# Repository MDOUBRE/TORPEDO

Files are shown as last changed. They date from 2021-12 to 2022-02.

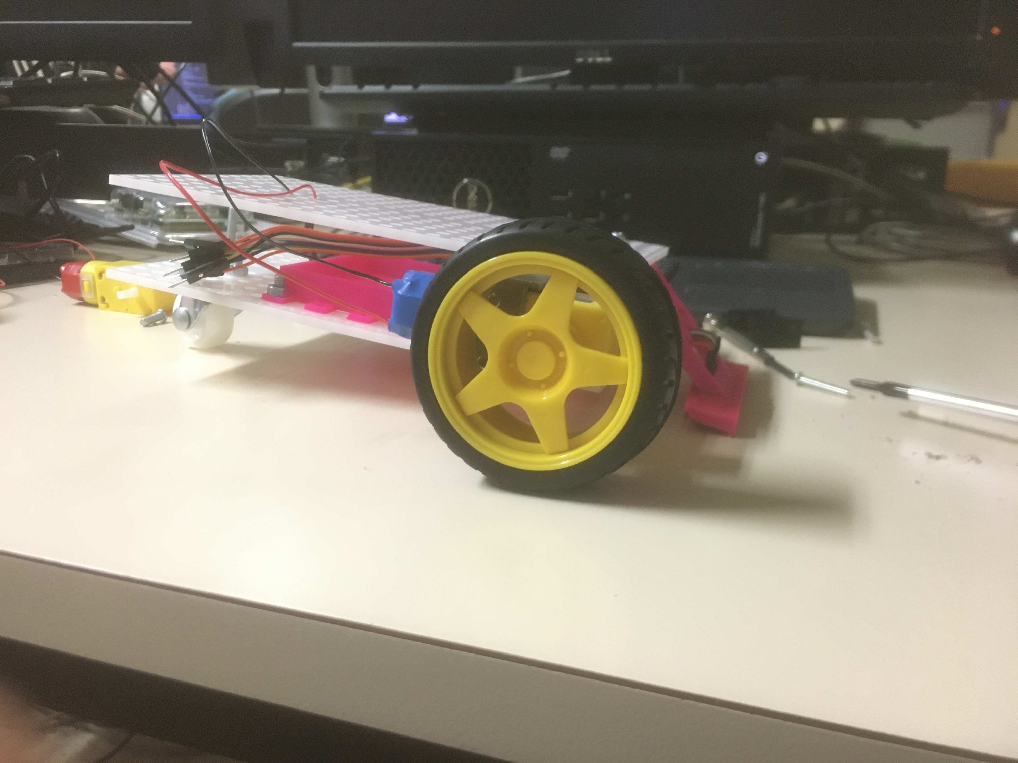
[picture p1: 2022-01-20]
Photos/chassis_v2_6.JPG

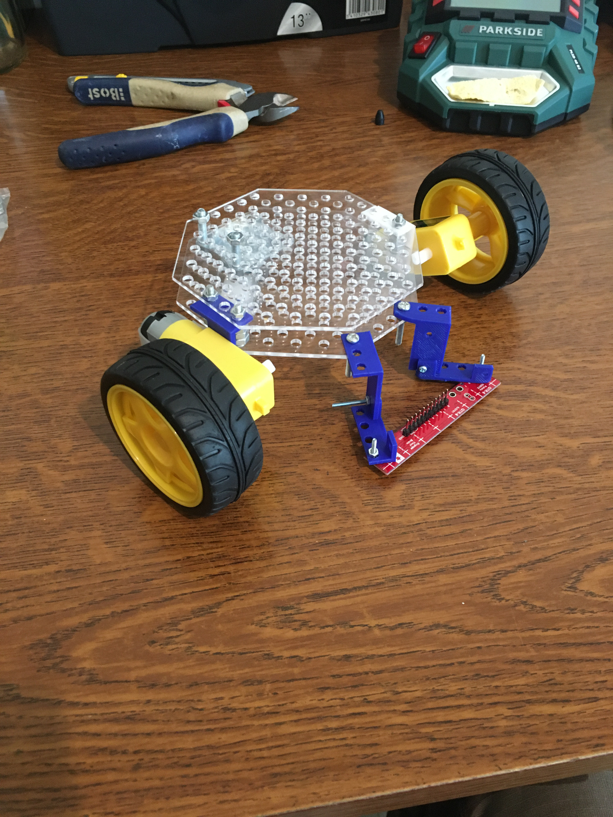
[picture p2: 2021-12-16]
Photos/chassis_v1_1.JPG

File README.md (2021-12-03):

# TORPEDO
Projet TORPEDO

Le projet Torpedo est une projet qui a pour but de concevoir et de réaliser un petit robot autonôme suiveur de lignes.

Il devra à la fin du projet être capable de bouger dans une grille en suivant des lignes et/ou en changeant de directions quand il passera sur un croisement jusqu'à trouver une case de couleur et d'y déposer une caisse de couleur identique.
Il y aura trois cases de couleur sur la grille.

Pour réaliser ce robot nous devrons relever plusieurs challenges :
- Suivi d'une ligne (droite ou courbe)
- Gestion des intersections
- Détection des couleurs
- Laché de caisse
- Mémorisation de grille en mémoire
- Algo du plus court chemin

Nous avons à notre disposition le matériel suivant :
- 1X STM32
- 2X moteurs
- 1X controlleur de moteurs
- 1X chassis (Fichiers STL)

Les membres de l'équipe sont :
- Maxime DOUBRE - Chef de projet
- Julien BERTRAND - Contributeur
- Guillaume DELOSIERES - Contributeur 
- Juan-Pablo GARCIA - Contributeur

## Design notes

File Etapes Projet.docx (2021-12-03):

Hardware (⅕)

- Châssis :
  - Impression (via STL Cassé) ⇒ Guillaume
  - Assemblage
- Électronique :
  - Soudure des pièces ⇒ Maxime
- Assemblage Châssis / Électronique (composants)
- Câblage

Software (⅗)

- Suivi de ligne ⇒ Maxime, Julien, Guillaume, Juan Pablo
- Intersection ⇒
- Sortie de route ⇒
- Détection des couleurs des cases
- Lâché de caisse
- Reconnaissance de grille dans la mémoire
- Plus court chemin (Dijkstra), ...

Tests (⅕)

- Test suivi de ligne : (⇒ Maxime, Julien, Guillaume, Juan Pablo)
  - ligne droite
  - courbe
- Test intersection :
  - X, T et L
- Test sortie de route
- Test couleurs
- Test lâché de caisses
- Test reconnaissance grille mémoire
- Test Dijkstra

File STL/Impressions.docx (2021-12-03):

FABLAB :

- 1 base
- 1 sensor x2 ( base et capteur )
- 1 moteur
- 1 moteur2
- 1 fixation ( plaque )

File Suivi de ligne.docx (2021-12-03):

Suivi de ligne

Fonctions :

- setMoteur(int, int)
- corrigerPosition

Dans le main dans while(True) et if(etat==avancer):

- On allume les moteurs
- captation capteurs ⇒ dans tableau global
- on appelle corrigerPosition
- On détecte intersection/couleur/sortie/... et changement état

setMoteur(int, int)

- on modifie la puissance envoyée aux moteurs selon valeur int
- vérifier que les int ne dépasse pas une certaine valeur et que ca dépasse pas 100% des moteurs ou -100%

corrigerPosition()

- selon captations on appelle setMoteur
- si tout va bien on appelle accélérer ⇒ setMoteur(+,+)

O O O O O O O O

1 2 3 4 5 6 7 8

Configuration des 8 capteurs lors du suivi de ligne.

- les capteurs 4 et 5 voient du noir
- les capteurs 1, 2, 7 et 8 voient du blanc
- les capteurs 3 et 6 voient du gris ou du blanc selon la largeur de la ligne

définir plusieurs niveaux de gris pour les capteurs

0 | 1 | 2 | 3 | 4 | 5 | 6
0-10 | 11-25 | 26-40 | 41-55 | 56-70 | 71-85 | 86-100

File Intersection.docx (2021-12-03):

Intersection

Fonctions :

- interuption si au moins 5 capteurs cote à cote dans le noir ⇒ etat => intersection (déjà ds le main donc à voir ou coder les interruptions)
- arreterRobot() ⇒ étatEnCours intersection (init, arret, arreté, action, sortie)
- decider()
- agir()

arretRobot() :

- regarder dans tableau global pourcentage moteur et décélérer en conséquence (baisse des moteurs proportionnelle à vitesse

tq % >0 on décrémente de int selon tableau

- changer état intersection ⇒ arreté

décider() :

- appeler les dijkstra et autres...
- par défaut : tourner à gauche si possible

agir() :

- setMoteur() Rotation jusqu’à être sur la nouvelle ligne à suivre et que les capteurs de gauche aient capté du noir si on tourne à gauche
- état = avancer

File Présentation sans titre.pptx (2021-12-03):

## TORPEDO

par un groupe dont on ne citera pas le nom parce qu’il est vraiment éclatax!

## Equipe

BERTRAND Julien - Contributeur
DELOSIERES Guillaume - Contributeur
GARCIA Juan Pablo - Contributeur
DOUBRE Maxime - Chef de projet

## Objectif

## Objectif

## Objectif

## Moyens

X2

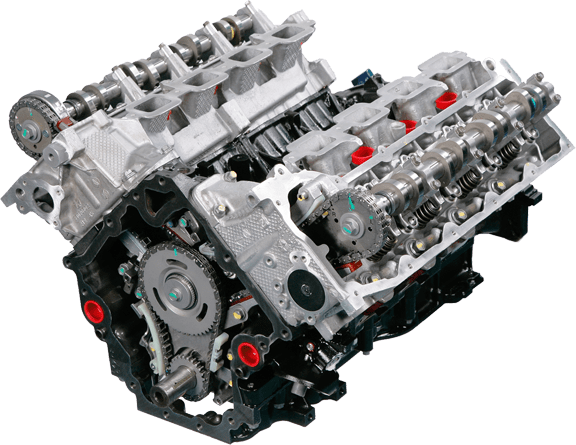
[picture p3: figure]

X1

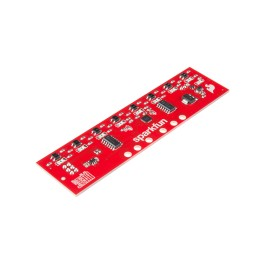
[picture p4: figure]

X1

## Comment ?

## Comment ?

## Comment ?

## Merci

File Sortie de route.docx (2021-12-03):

Sortie de route

Fonctions :

- interruption tout est blanc si pas en état intersection
- arreterRobot()
- demiTour() => on rotate jusqu’à retrouver ligne ou certain nombre de seconde
- spirale() si ligne pas retrouvée

arreterRobot() : voir ds Intersection

demiTour() :

- setMoteur(x, -x) pendant un certain temps ou alors jusqu’à ligne

spirale():

- setMoteur(x, -x) tourner en spirale jusqu’à retrouver une ligne

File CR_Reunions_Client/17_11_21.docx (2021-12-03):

CR Réunion 17 novembre 2021

Sujet : Présentation du sujet de projet, explication de son contenu et fourniture du matériel

Présents :

Client : CASSE Hugues

Equipe Projet : DOUBRE Maxime, BERTRAND Julien, DELOSIERES Guillaume, GARCIA Juan Pablo

Déroulé :

M.CASSE nous a présenté l’ensemble du projet, quel en était l’objectif et ce que nous devions faire pour y parvenir.

Il nous a fourni le matériel nécessaire pour commencer à le mener.

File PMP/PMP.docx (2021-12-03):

DOUBRE Maxime ⇒ Chef de projet

BERTRAND Julien ⇒ Attributeur, Contributeur

DELOSIERES Guillaume ⇒ Contributeur

GARCIA Juan Pablo ⇒ Contributeur

PMP TORPEDO

Table des matières

1. Contexte et objectifs
  a. Projet
  b. Document
  c. Répartition des rôles
2. Avancement du projet
  a. Planning
  b. Liste des tâches techniques
  c. Contraintes du client
3. Réunions
  a. Réunions périodiques avec le client
4. Documents
5. Livrables
6. Qualité
  a. Tests

1. Contexte et objectifs

a. Projet
b. Document
c. Répartition des rôles

DOUBRE Maxime ⇒ Chef de projet

BERTRAND Julien ⇒ Attributeur, Contributeur

DELOSIERES Guillaume ⇒ Contributeur

GARCIA Juan Pablo ⇒ Contributeur

5. Livrables

- Châssis robot
- Code Suivi ligne
- Code Intersection
- Code couleurs et largage caisse
- Code mémoire grille
- Code Dijkstra

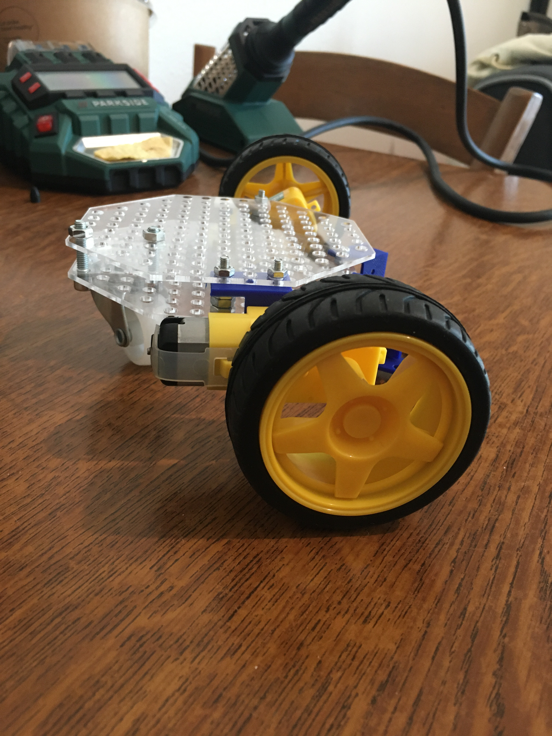
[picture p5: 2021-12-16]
Photos/chassis_v1_3.JPG

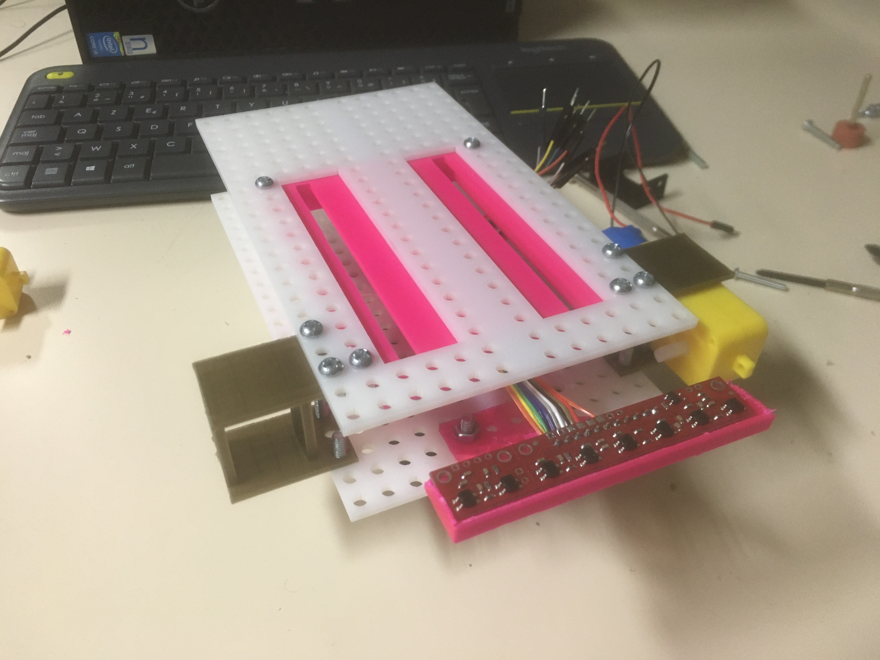
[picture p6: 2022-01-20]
Photos/chassis_v2_1.JPG

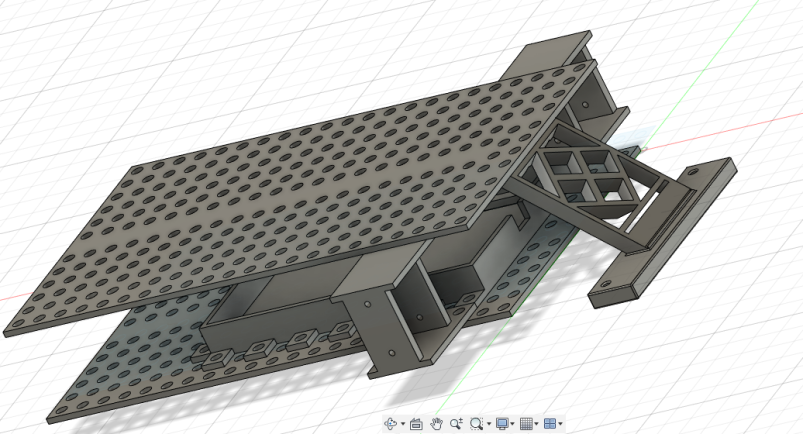
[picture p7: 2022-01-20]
Photos/chassis_v2_stl.png

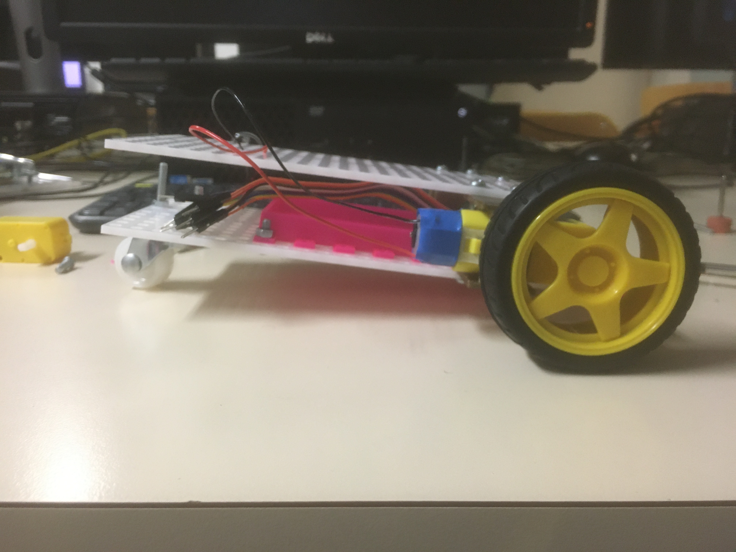
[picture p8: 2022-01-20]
Photos/chassis_v2_5.JPG

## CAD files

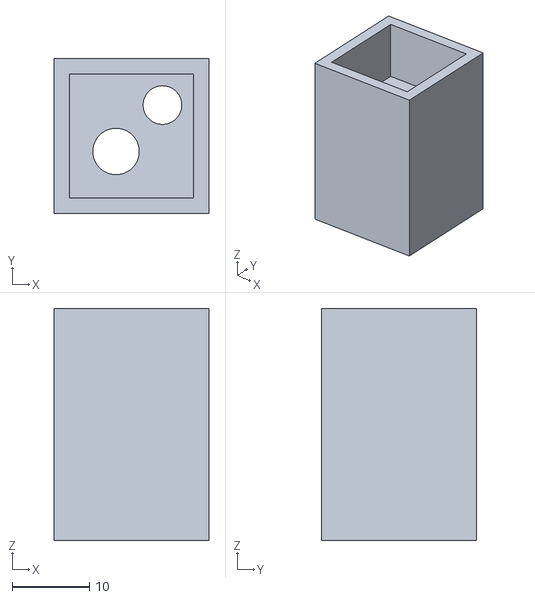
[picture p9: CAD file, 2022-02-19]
STL/detecteur couleur v0.stl
20.0 x 20.0 x 30.0

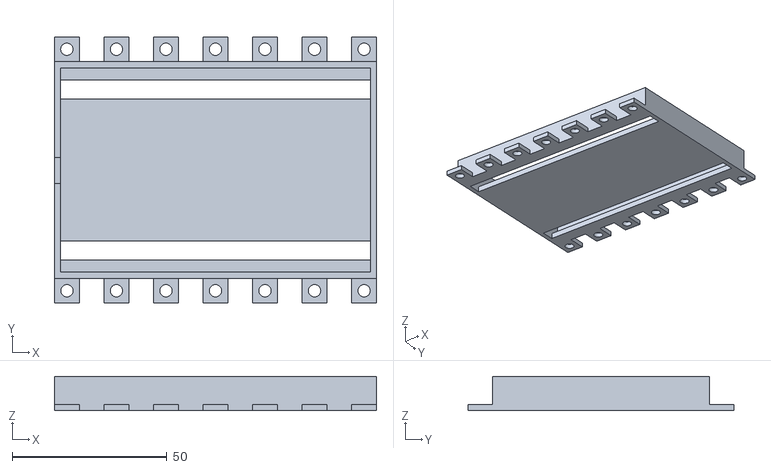
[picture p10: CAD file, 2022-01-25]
STL/bases stm32.stl
104.0 x 86.0 x 11.0

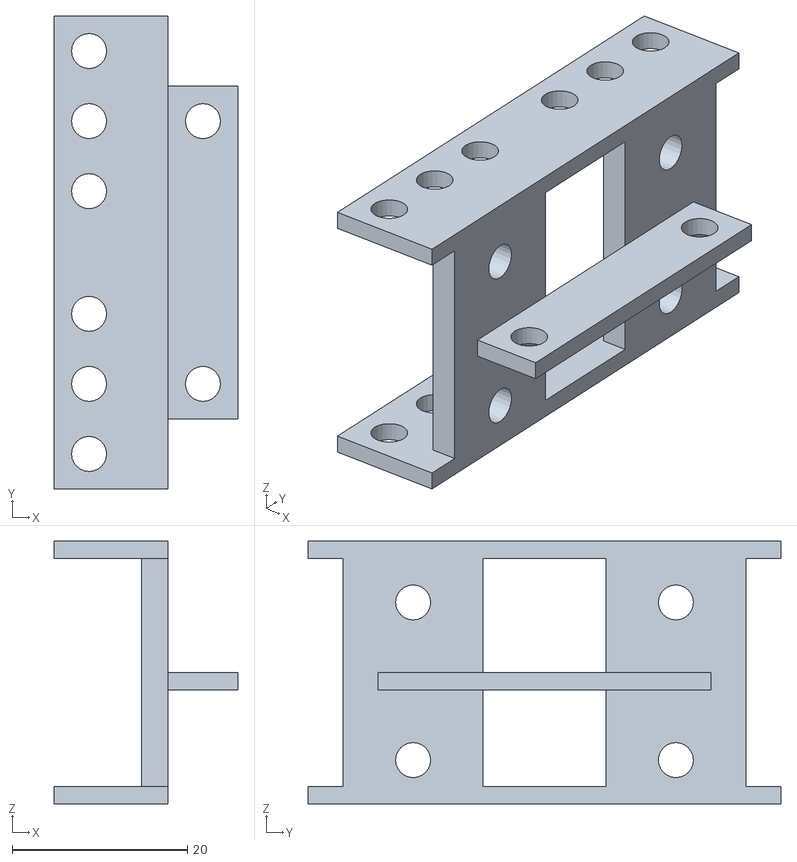
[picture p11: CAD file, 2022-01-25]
STL/roue arriere.stl
21.0 x 54.0 x 30.0

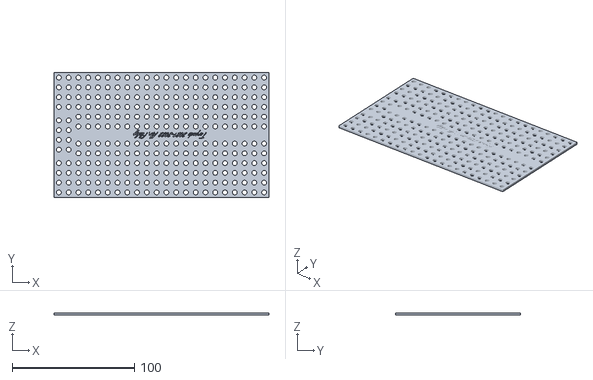
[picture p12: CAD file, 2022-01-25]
STL/Base Haute .stl
176.0 x 102.0 x 2.00

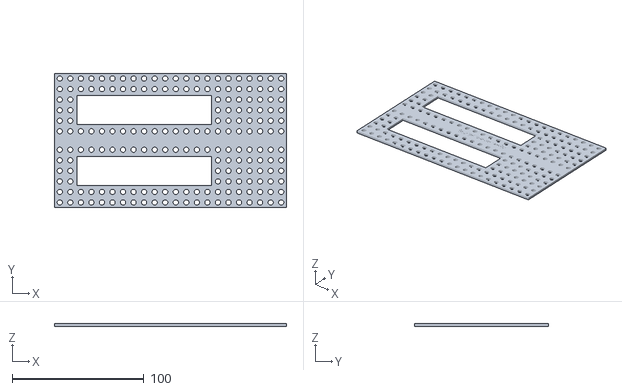
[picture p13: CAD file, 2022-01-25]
STL/Base Bas.stl
176.0 x 102.0 x 2.00

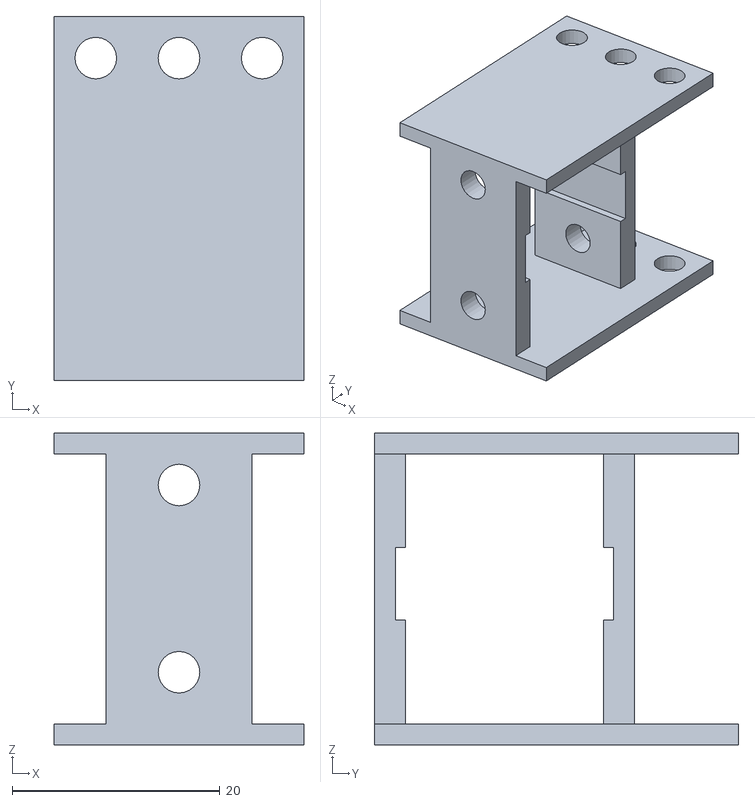
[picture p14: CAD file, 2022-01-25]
STL/Support Moteur V3.stl
24.0 x 35.0 x 30.0

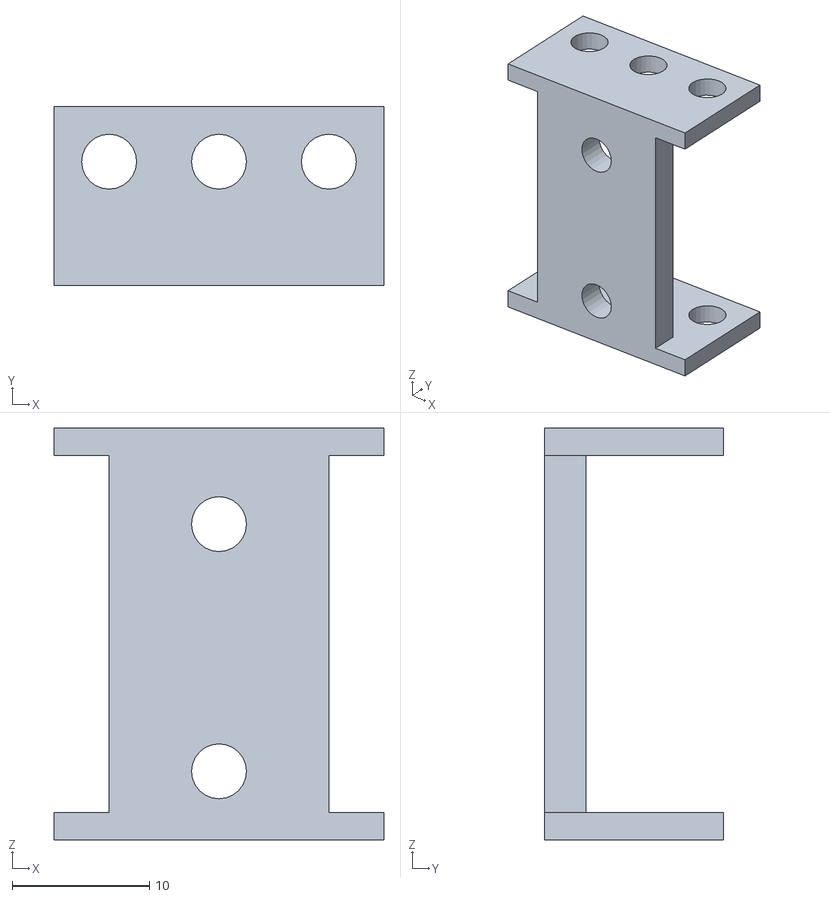
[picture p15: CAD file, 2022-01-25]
STL/Support Moteur Small.stl
24.0 x 13.0 x 30.0

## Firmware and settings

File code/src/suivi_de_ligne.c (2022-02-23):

#include <tinyprintf.h>
#include <stm32f4/rcc.h>
#include <stm32f4/gpio.h>
#include <stm32f4/nvic.h>
#include <stm32f4/exti.h>
#include <stm32f4/syscfg.h>
#include <stm32f4/tim.h>
#include <stm32f4/adc.h>


// GPIOD
//#define X P
#define C1 0                            
#define C2 1                            
#define C3 2                            
#define C4 3                            
#define C5 4                            
#define C6 5                           
#define C7 6                            
#define C8 7    


// GPIODA

#define WAIT_PSC 1  //T * 42MHz / 2¹⁶
#define WAIT_DELAY (APB1_CLK / WAIT_PSC)
#define HALF_PERIOD 42000

#define SEUIL_BLANC	4
#define SEUIL_NOIR	8

volatile int puiss_MD = 0; //[0-100] puissance moteur droit
volatile int puiss_MG = 0; //[0-100] puissance moteur gauche
int sens_MD = 0; //[0,1] sens moteur droit
int sens_MG = 0; //[0,1] sens moteur gauche

#define MD1 4
#define MD2 6
#define MG1 5
#define MG2 7
#define MODE 8

#define SM 4

#define TIM3_DIV 8
#define TIM3_PERIOD	60000

#define KP_MD
#define KI_MD
#define KD_MD
#define KP_MG
#define KI_MG
#define KD_MG

volatile int un_sur_deux = 0;
volatile int TIM4_triggered = 0;
volatile int KP = 144; //Constante Proportionnelle
volatile int P = 0 ; // Error
volatile int KI = 1; //Constante Integrale
volatile int I = 0; //I = I + error (P)
volatile int KD = 108; //Constante Derivée
volatile int D = 0; //D= error - previousError 
volatile int PAvant = 0; // Previous error
volatile int PID = 0;
volatile enum{ OUT,LINE,INTERSECTION} etat = OUT;
volatile enum{ T,LL,LR,X,TL,TR,TR1,TR2,TR3,TL1,TL2,TL3} type = T;
volatile int d = 0;
volatile short int demitour = 0;


// Variable du chemin

volatile enum{ N, E, S ,O} direction = O; // direction de depart
#define TAILLE_GRILLE 30 // <= 32 ; Nombre de points de la grille, inférieur ou égale à 32
#define CHEMIN_MAX 10    // Nombre de points du chemin, inférieur ou égale à 32,
//tableau contenant une suite de direction 
//Il sert à guider le véhicule entre 2 points clés du chemin
volatile short int chemin[TAILLE_GRILLE];
// Points clés du chemin
// le vehicule s'arrètera au dernier point du tableau ou à la première occurence de -1
// le premier point du tableau est le premier point rencontré
// attention à bien orienté le véhicule
volatile short int checkpoint[CHEMIN_MAX] = {12 , 10  , 0 , 4 , 29 , 25 , 10 , 14 , 13 , -1};
// largage de caisse
// le vehicule activera le servo-moteur quand il y a une valeur differente de 0
// le premier point de TAB_SM correspond au premier point de checkpoint
volatile short int TAB_SM[CHEMIN_MAX] =     {0 ,  0  , 1  ,  0 , 1 , 0  , 0  , 0  , 0 , 0 };


// calcul du temps entre de le moment ou la ligne d'un capteur est montee a 1 et le moment ou elle retombe a 0
// passer la ligne du capteur en outpout avec pull up
// attendre 10 microseconde pour que la ligne soit a 1
// passer la ligne en inpout -> la tension de la ligne va diminuer jusqu'a etre nulle 
// calculer le temps de descente a 0

// structure de représentation des points
// chaque point est représenté par ces voisins orientés
struct croisement
{
    int nord; //point au nord du sommet
    int est; //point à l'est du sommet
    int ouest; //point à l'ouest du sommet
    int sud; //point au sud du sommet
};
typedef struct croisement croisement;


//fonction d'analyse du retour capteur
// retourne une valeur entre -7 et +7 pour le PID afin de corriger le décalage par rapport à la ligne
// retourne 10 en cas de sortie de route
// retourne 11 en cas de croisement en T
// retourne 12 en cas de virage à gauche
// retourne 13 en cas de virage à droite
int get_error(short int * array){

	unsigned char TB = 0b00000000;
	unsigned char TBT;
	for (short int i =0 ; i < 8; i++){
		TB = TB << 1;
		printf("%d\n", array[i]);
		if (array[i]> 6){
			TB = TB | 0b00000001;
		}
		
	}
	printf("%u\n",TB);
	if (!(TB ^ 0b00011000))
	{
		return 0;
	}else if(!(TB ^ 0b00001000))
	{
		return 1;
	}else if(!(TB ^ 0b00001100))
	{
		return 2;
	}else if(!(TB ^ 0b00000100))
	{
		return 3;
	}else if(!(TB ^ 0b00000110))
	{
		return 4;
	}else if(!(TB ^ 0b00000010))
	{
		return 5;
	}else if(!(TB ^ 0b00000011))
	{
		return 6;
	}else if(!(TB ^ 0b00000001))
	{
		return 7;
	}else if(!(TB ^ 0b00010000))
	{
		return -1;
	}else if(!(TB ^ 0b00110000))
	{
		return -2;
	}else if(!(TB ^ 0b00100000))
	{
		return -3;
	}else if(!(TB ^ 0b01100000))
	{
		return -4;
	}else if(!(TB ^ 0b01000000))
	{
		return -5;
	}else if(!(TB ^ 0b11000000))
	{
		return -6;
	}else if(!(TB ^ 0b10000000))
	{
		return -7;
	}else if(!(TB ^ 0b00000000))
	{
		return 10;
	}else
	{
		TBT = (TB & 0b11111000);
		if(!(TBT ^ 0b11111000) || !(TBT ^ 0b11110000) || !(TBT ^ 0b11101000) || !(TBT ^ 0b11011000) || !(TBT ^ 0b10111000) || !(TBT ^ 0b01111000)) 
		{
			TBT = (TB & 0b00011111);
			if(!(TBT ^ 0b00011111) || !(TBT ^ 0b00011110) || !(TBT ^ 0b00011101) || !(TBT ^ 0b00011011) || !(TBT ^ 0b00010111) || !(TBT ^ 0b000001111)) 
			{
				return 11;
			}
			return 12;
		}else 
		{
			TBT = (TB & 0b00011111);
			if(!(TBT ^ 0b00011111) || !(TBT ^ 0b00011110) || !(TBT ^ 0b00011101) || !(TBT ^ 0b00011011) || !(TBT ^ 0b00010111) || !(TBT ^ 0b000001111)) 
			{
				return 13;
			}
		}
	}
	return 0;
}

void handle_TIM4() {
	TIM4_ARR = HALF_PERIOD;
    if(un_sur_deux!=1){    
		TIM4_triggered = 1;
        
        un_sur_deux+=1;
    }
    else{
        un_sur_deux=0;
    }
	
	TIM4_SR &= ~TIM_UIF;
}

void init_TIM4(){
	DISABLE_IRQS;

	NVIC_ICER(TIM4_IRQ >> 5) |= 1 << (TIM4_IRQ & 0X1f);
	NVIC_IRQ(TIM4_IRQ) = (uint32_t)handle_TIM4;
	NVIC_IPR(TIM4_IRQ) = 0;

	NVIC_ICPR(TIM4_IRQ >> 5) |= 1 << (TIM4_IRQ & 0X1f);
	NVIC_ISER(TIM4_IRQ >> 5) |= 1 << (TIM4_IRQ & 0X1f);

	TIM4_CR1 = 0;
	TIM4_PSC = WAIT_PSC;
	TIM4_ARR = HALF_PERIOD;
	TIM4_EGR = TIM_UG;
	TIM4_SR = 0;
	TIM4_CR1 = TIM_ARPE;
	TIM4_SR &= ~TIM_UIF;
	TIM4_DIER = TIM_UIE;

	ENABLE_IRQS;
	TIM4_CR1 |= TIM_CEN;
}


void init(){
    
	

}

// fonction de charge des capteurs
// Fait passer toutes les lignes des capteurs en OUT et PULL UP
void CHARGE()
{
	for (short int i=0; i < 4; i++)                              
	{
		GPIOA_MODER = SET_BITS(GPIOA_MODER, i*2, 2, 0b01); //set GPIO A 
		GPIOA_OTYPER = GPIOA_OTYPER & ~(1 << i);
		GPIOA_PUPDR = SET_BITS(GPIOA_PUPDR, i*2, 2, 0b01);

		GPIOD_MODER = SET_BITS(GPIOD_MODER, i*2, 2, 0b01); //set GPIO D
		GPIOD_OTYPER = GPIOD_OTYPER & ~(1 << i);
		GPIOD_PUPDR = SET_BITS(GPIOD_PUPDR, i*2, 2, 0b01);
	}
}

// fonction de charge des capteurs
// Fait passer toutes les lignes des capteurs en IN et PULL UP

void CAPTURE_START()
{
	for (short int i=0; i < 4; i++)                             
	{
		GPIOA_MODER = SET_BITS(GPIOA_MODER, i*2, 2, 0b00); //set GPIO A 
		GPIOA_OTYPER = GPIOA_OTYPER & ~(1 << i);
		GPIOA_PUPDR = SET_BITS(GPIOA_PUPDR, i*2, 2, 0b01);

		GPIOD_MODER = SET_BITS(GPIOD_MODER, i*2, 2, 0b00); //set GPIO D
		GPIOD_OTYPER = GPIOD_OTYPER & ~(1 << i);
		GPIOD_PUPDR = SET_BITS(GPIOD_PUPDR, i*2, 2, 0b01);
	}
	
}

void init_moteurs(){
    //init des deux pins pour le moteur 1
    GPIOB_MODER = SET_BITS(GPIOB_MODER, 2*MD1, 2, 0b10);
    GPIOB_AFRL = SET_BITS(GPIOB_AFRL, 4*MD1, 4, 2);
    GPIOB_OTYPER &= ~(1 << MD1);
    GPIOB_MODER = SET_BITS(GPIOB_MODER, 2*MD2, 2, 0b01);
	GPIOB_OTYPER &= ~(1 << MD2);
	GPIOB_PUPDR = SET_BITS(GPIOB_PUPDR, 2*MD2, 2, 0b01);

    // init des deux pins pour le moteur 2
    GPIOB_MODER = SET_BITS(GPIOB_MODER, 2*MG1, 2, 0b10);
    GPIOB_AFRL = SET_BITS(GPIOB_AFRL, 4*MG1, 4, 2);
    GPIOB_OTYPER &= ~(1 << MG1);
    GPIOB_MODER = SET_BITS(GPIOB_MODER, 2*MG2, 2, 0b01);
	GPIOB_OTYPER &= ~(1 << MG2);
	GPIOB_PUPDR = SET_BITS(GPIOB_PUPDR, 2*MG2, 2, 0b01);

    // init de la pin pour le mode
    GPIOD_MODER = SET_BITS(GPIOD_MODER, 2*MODE, 2, 0b01);
	GPIOD_OTYPER &= ~(1 << MODE);
	GPIOD_PUPDR = SET_BITS(GPIOD_PUPDR, 2*MODE, 2, 0b01);

    GPIOD_BSRR = 1 << MODE;
}

// pour le moment 20KHz
void init_TIM3() {
	// TIM3
    TIM3_PSC = 0;
	TIM3_ARR = 0xE0F;
	TIM3_CCMR1 = TIM_CCS1S_OUT | TIM_OC1M_PWM1 | TIM_CCS2S_OUT | TIM_OC2M_PWM1;
    //TIM3_CCMR2 = TIM_CCS2S_OUT | TIM_OC2M_PWM1;
	TIM3_CCER = TIM_CC1E | TIM_CC2E;
	TIM3_CCR1 = 0;
	TIM3_CCR2 = 0;
	TIM3_CR1 = TIM_CEN | TIM_ARPE;
    //TIM3_CR2 = TIM_CEN | TIM_ARPE;
}

void start_MD() {
	TIM3_CCR1 = TIM3_ARR;
}

void stop_MD() {
	TIM3_CCR1 = 0;
}

void set_MD(int pulse) {

	puiss_MD = pulse;
    TIM3_CCR1 =pulse;
	//TIM3_CCR1 = 0;
}

void inverseMD(){
    if(GPIOB_ODR & (1<<MD2)){
        GPIOB_BSRR = 1 << (MD2 + 16);
    }
    else{
        GPIOB_BSRR = 1 << MD2;

    }
}

void start_MG() {
	TIM3_CCR2 = TIM3_ARR;
}

void stop_MG() {
	TIM3_CCR2 = 0;
}

void set_MG(int pulse) {

	puiss_MG = pulse;
	TIM3_CCR2 = pulse;//TIM_ARR = 20k, TIM_CCR2 va de 0 a 20k
	//TIM3_CCR2 = 0;
}

void inverseMG(){
    if(GPIOB_ODR & (1<<MG2)){
        GPIOB_BSRR = 1 << (MG2 + 16);
    }
    else{
        GPIOB_BSRR = 1 << MG2;
    }
}

//Actualise la vitesse des moteurs en fonction du PID
void VITESSE_PID()
{
	printf("In PID\n");
	puiss_MD = 1080 -PID; //30 % de 3600
	if (puiss_MD <0){
		puiss_MD = 0;
	}
	puiss_MG = 1980 - puiss_MD;
	set_MD(puiss_MD);
	set_MG(puiss_MG);
	
	printf("Vitesse M1: %d, Vitesse M2 %d\n", puiss_MD, puiss_MG);
}

//Diminue légèrement la vitesse des moteurs
//Comme la fonction est appelée à chaque cycle, cela permet un arret doux du véhicule
void SMOOTHSTOP()
{
	if(puiss_MD >= 25)
	{
		set_MD(puiss_MD - 25);
        if(puiss_MD >= 25 + puiss_MG)
        {
            set_MG(puiss_MD - 25);
        }
	}
	else
	{
		set_MD(0);
	}
	if(puiss_MG >= 25)
	{
		set_MG(puiss_MG - 25);
        if(puiss_MG >= 25 + puiss_MD)
        {
            set_MG(puiss_MG - 25);
        }
	}
	else
	{
		set_MG(0);
	}
    

}

int calculer_chemin(short int start, short int end);
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
int main() {
	printf("\nStarting...\n");

	// RCC init
	RCC_AHB1ENR |= RCC_GPIOAEN;
	RCC_AHB1ENR |= RCC_GPIODEN;
	RCC_APB1ENR |= RCC_TIM4EN;
	RCC_APB2ENR |= RCC_ADC1EN;
	RCC_AHB1ENR |= RCC_GPIOBEN;
	RCC_APB1ENR |= RCC_TIM3EN;



	// initialisation
	init();
    init_TIM4();
	init_moteurs();
    init_TIM3();
    init_TIM2();
    init_SM();

    if(GPIOB_ODR & (1<<MD2)){
        sens_MD = 0;
    }
    else{
        sens_MD = 1;
    }
    if(GPIOB_ODR & (1<<MG2)){
        sens_MG = 0;
    }
    else{
        sens_MG = 1;
    }

    // calcul chemin du premier trajet entre les deux premiers points clés
    
    printf("initialisation finie\n");

    short int start = checkpoint[d];
    short int end = checkpoint[d+1];

    short int c = calculer_chemin(start,end);
	// main loop
	printf("Endless loop!\n");
    short int x=0;
    int error = 0;
    CHARGE();
    short int vc[8] = { 12 , 12 , 12 , 12 , 12 , 12 , 12 , 12 };
	set_MG(30);
	set_MD(30);
	while(1) {
        if(TIM4_triggered){
			TIM4_triggered = 0;
            //charge les capteurs pendant un cycle puis regarde sur les 10 cycles suivants combien de temps les lignes mettent à se décharger
			for (int i=0; i < 4; i++)                              
            {
                if((vc[i] > x) & ((GPIOA_IDR & (1 << i ))== 0))
                {
                    vc[i] = x;
                }
                if((vc[i+4] > x) & ((GPIOD_IDR & (1 << i ))== 0))
                {
                    vc[i+4] = x;
                }
            }
            if (x == 11)
            {
                
                x = 0;
                printf("%d ; %d ; %d ; %d ; %d ; %d ; %d ; %d\n",vc[0],vc[1],vc[2],vc[3],vc[4],vc[5],vc[6],vc[7]);
                CHARGE();
                switch(etat){
                // cas sortie de route
                case OUT :
					printf("CASE OUT");
                    // passage en suivi de ligne si le véhicule détecte une ligne
                    if  ((vc[3] > SEUIL_NOIR || vc[4] > SEUIL_NOIR) && vc[0] < SEUIL_BLANC && vc[7] < SEUIL_BLANC ){
                        etat = LINE;
						PAvant = 0;
						I = 0;
                        break;
                    }
                    stop_MD();
                    stop_MG();
                    break;
                // cas suivi de ligne
                case LINE:
					printf("CASE LINE");
                    error = get_error(vc);
                    switch(error){
                        // passage en sortie de route
                        case 10:
                            etat = OUT;
                            stop_MD();
                            stop_MG();
                            break;
                        // passage en intersection en T
                        case 11:
                            etat = INTERSECTION;
                            type = T;
                            stop_MD();
                            stop_MG();
                            break;
                        // passage en intersection en L à gauche
                        case 12:
                            etat = INTERSECTION;
                            type = LL;
                            stop_MD();
                            stop_MG();
                            break;
                        // passage en intersection en L à droite
                        case 13:
                            etat = INTERSECTION;
                            type = LR;
                            stop_MD();
                            stop_MG();
                            break;
                        default:
                            P = error;
                            I = I + P;
                            D = P - PAvant;
                            PID = (KP*P) +(KI*I)+ (KD*D);
                            PAvant = P;
                            printf("P: %d, result get_error: %d\n",P,get_error(vc));
                            VITESSE_PID();
                            break;
                    }
                    break;
                // cas intersection
                case INTERSECTION:
                    printf("CASE INTERSECTION\n");
                    
                    switch(type){
                        // sous cas intersection en T
                        case T:
                            printf("CASE T\n");
                            SMOOTHSTOP();
                            // passage en intersection en X
                            if(vc[7] < SEUIL_BLANC && vc[0] < SEUIL_BLANC && (vc[3] > SEUIL_BLANC || vc[4] > SEUIL_BLANC))
                            {
                                type = X;
                                //printf("CX\n");
                            }
                            // quand le véhicule est arrété, appelle la fonction de choix de direction
                            if( puiss_MD == 0 && puiss_MG == 0)
                            {
                                c = choix_direction(c, chemin);
                            }
                            break;
                        // sous cas intersection en L à gauche
                        case LL:
                            printf("CASE LL\n");
                            SMOOTHSTOP();
                            // passage en intersection en T
                            if(vc[7] > SEUIL_NOIR && (vc[3] > SEUIL_BLANC || vc[4] > SEUIL_BLANC))
                            {
                                type = T;
                                //printf("CT\n");
                            }
                            // passage en intersection en T à gauche
                            if(vc[0] < SEUIL_BLANC && (vc[3] > SEUIL_BLANC || vc[4] > SEUIL_BLANC))
                            {
                                type = TL;
                                //printf("CTL\n");
                            }
                            // quand le véhicule est arrété, appelle la fonction de choix de direction
                            if( puiss_MD == 0 && puiss_MG == 0)
                            {
                                c = choix_direction(c, chemin);
                            }
                            break;
                        // sous cas intersection en L à droite
                        case LR:
                            printf("CASE LR\n");
                            SMOOTHSTOP();
                            // passage en intersection en T
                            if(vc[0] > SEUIL_NOIR && (vc[3] > SEUIL_BLANC || vc[4] > SEUIL_BLANC))
                            {
                                type = T;
                                //printf("CT\n");
                            }
                            // passage en intersection en T à droite
                            if(vc[7] < SEUIL_BLANC && (vc[3] > SEUIL_BLANC || vc[4] > SEUIL_BLANC))
                            {
                                type = TR;
                                //printf("CTR\n");
                            }
                            // quand le véhicule est arrété, appelle la fonction de choix de direction
                            if( puiss_MD == 0 && puiss_MG == 0)
                            {
                                c = choix_direction(c, chemin);
                            }
                            break;
                        //sous cas intersection en X
                        case X:
                            printf("CASE X\n");
                            SMOOTHSTOP();
                            // quand le véhicule est arrété, appelle la fonction de choix de direction
                            if( puiss_MD == 0 && puiss_MG == 0)
                            {
                                c = choix_direction(c, chemin);
                            }
                            break;
                        //sous cas intersection en T à gauche
                        case TL:
                            printf("CASE TL\n");
                            SMOOTHSTOP();
                            // quand le véhicule est arrété, appelle la fonction de choix de direction
                            if( puiss_MD == 0 && puiss_MG == 0)
                            {
                                c = choix_direction(c, chemin);
                            }
                            break;
                        //sous cas intersection en T à droite
                        case TR:
                            printf("CASE TR\n");
                            SMOOTHSTOP();
                            // quand le véhicule est arrété, appelle la fonction de choix de direction
                            if( puiss_MD == 0 && puiss_MG == 0)
                            {
                                c = choix_direction(c, chemin);
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

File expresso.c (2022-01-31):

// LED on GPIOD
#define ONOFF_LED		12
#define STARTSTOP_LED	13

// button on GPIOA
#define ONOFF_BUT		PA3
#define STARTSTOP_BUT	P4		

void init_ui() {

	// LEDs
	GPIOD_MODER = SET_BITS(GPIOD_MODER, 2*ONOFF_LED, 2, GPIOD_MODER_OUT);
	GPIOD_OTYPER ~= 1 << ONOFF_LED;
	GPIOD_PUPDR = SET_BITS(GPIOD_PUPDR, 2*ONOFF_LED, 2, GPIOD_PUPDR_PU);
	GPIOD_BSSR = (1 << (16 + ONOFF_LED));
	GPIOD_MODER = SET_BITS(GPIOD_MODER, 2*STARTSTOP_LED, 2, GPIOD_MODER_OUT);
	GPIOD_OTYPER ~= 1 << STARTSTOP_LED;
	GPIOD_PUPDR = SET_BITS(GPIOD_PUPDR, 2*STARTSTOP_LED, 2, GPIOD_PUPDR_PU);
	GPIOD_BSSR = (1 << (16 + STARTSTOP_LED));

	// buttons
	GPIOA_MODER = SET_BITS(GPIOA_MODER, 2*ONOFF_BUT, 2, GPIOD_MODER_IN);
	GPIOA_PUPDR = SET_BITS(GPIOA_PUPDR, 2*ONOFF_BUT, 2, GPIOD_PUPDR_PU);
	GPIOA_MODER = SET_BITS(GPIOA_MODER, 2*STARTSTOP_BUT, 2, GPIOD_MODER_IN);
	GPIOA_PUPDR = SET_BITS(GPIOA_PUPDR, 2*STARTSTOP_BUT, 2, GPIOD_PUPDR_PU);
}

void set_onoff_led(int s) {
	if(s == 1)
		GPIOD_BSRR = 1 << ONOFF_LED;
	else
		GPIOD_BSRR = 1 << (16 + ONOFF_LED);
}

void set_startstop_led(int s) {
	if(s == 1)
		GPIOD_BSRR = 1 << STARTSTOP_LED;
	else
		GPIOD_BSRR = 1 << (16 + STARTSTOP_LED);	
}

int test_onoff_button() {
	static int pushed = 0;
	if((GPIOA_IDR & (1 << ONOFF_BUT)) == 1)
		pushed = 1;
	else if(pushed) {
		pushed = 0;
		return 1;
	}
	return 0;
}

int test_startstop_button() {
	static int pushed = 0;
	if((GPIOA_IDR & (1 << STARTSTOP_BUT)) == 1)
		pushed = 1;
	else if(pushed) {
		pushed = 0;
		return 1;
	}
	return 0;
}


// Themo-resistror and pump (GPIOB)
// TIM3_CH1
#define THERM_PIN	4
// TIM3_CH2
#define PUMP_PIN	5
#define TIM3_DIV	7
#define TIM3_PERIOD	60000

// period 10ms
void init_TIM3() {

	// GPIOB
	GPIOB_MODER = SET_BITS(GPIOB_MODER, 2*THERM_PIN, 2, GPIOD_MODER_ALT);
	GPIOB_AFRL = SET_BITS(GPIOB_AFRL, 4*THERM_PIN, 4, 2);
	GPIOB_MODER = SET_BITS(GPIOB_MODER, 2*PUMP_PIN, 2, GPIOD_MODER_ALT);
	GPIOB_AFRL = SET_BITS(GPIOB_AFRL, 4*PUMP_PIN, 4, 2);

	// TIM3
	TIM3_CCR1 = 0;
	TIM3_ARR = TIM3_PERIOD;
	TIM3_PSC = TIM3_DIV - 1;
	TIM3_CCMR1 = TIM_OC1S_OUT | TIM_OC1M_PWM1
			   | TIM_OC2S_OUT | TIM_OC2M_PWM1;
	TIM3_CCER = TIM_CC1E | TIM_CC2E;
	TIM3_CCR1 = 0;
	TIM3_CCR2 = 0;
	TIM3_CR1 = TIM_CEN | CIM_ARPE;
}

void start_heater() {
	TIM3_CC1R = TIM3_PERIOD;
}

void stop_heater() {
	TIM3_CC1R = 0;
}

void start_pump() {
	TIM3_CC2R = PUMP_PERIOD;
}

void stop_pump() {
	TIM3_CC2R = 0;
}

void set_heater(int n) {
	TIM3_CC1R = n * TIM3_PERIOD / 100;
}

void set_pump(int n) {
	TIM3_CC2R = n * TIM3_PERIOD / 100;
}


// ADC (GPIOA) (IM8)
// therm sensor - ADC1_IN1
#define THERM_SENS_PIN	1
// pressure sensor - ADC2_IN2
#define PRESS_SENS_PIN	2

#define KP_THERM
#define KI_THERM
#define KD_THERM
#define KP_PRESS
#define KI_PRESS
#define KD_PRESS

int ready = 0;

void init_sensors() {

	// GPIOA
	GPIOA_MODER = SET_BITS(GPIOA_MODER, THERM_SENS_PIN*2, 2, GPIO_MODER_ANA);
	GPIOA_MODER = SET_BITS(GPIOA_MODER, PRESS_SENS_PIN*2, 2, GPIO_MODER_ANA);

	// ADC
	ADC1_SR = 0;
	ADC1_CR1 = ADC_EOCIE;
	//ADC1_CR2 = ADC_T8TRGO;
	ADC1_SQR3 = 1;
	ADC2_SR = 0;
	ADC2_CR1 = ADC_EOCIE;
	//ADC2_CR2 = ADC_T8TRGO;
	ADC1_SQR3 = 2;
	
	// TIM4
	TIM4_CR1 = 0;
	TIM4_PSC = 1000;
	TIM4_ARR = APB1_CLK/1000/10;
	TIM4_CR1 = ADC_CEN;

	// NVIC
	NVIC_ICER(ID_ADC & 0x1f) =  ID_ADC >> 5;
	NVIC_IPR(ADC_IRQ) = 0;
	NVIC_IRQ(ADC_IRQ) = handle_adc;
	NVIC_ISER(ID_ADC & 0x1f) =  ID_ADC >> 5; 
}

void start_therm_pid() {
	ADC1_CR2 = ADC_T8TRGO;
}

void stop_therm_pid() {
	ADC1_CR2 = 0;
}

void start_pump_pid() {
	ADC2_CR2 = ADC_T8TRGO;
}

void stop_pump_pid() {
	ADC2_CR2 = 0;
}

void handle_adc() {

	if((ADC1_SR & ADC_EOC) != 0) {
		static int sum = 0, ep = 0;
		int e = ADC1_DC - THERM_REF;
		int u = KP_THERM * e + KI_THERM * sum + KD_THERM * (e - ep);
		if(u < 0)
			u = 0;
		if(u > 100)
			u = 100;
		set_heater(u);
		if(e <= 0)
			ready = 1;
	}

	if((ADC2_SR & ADC_EOC) != 0) {
		static int sum = 0, ep = 0;
		int e = ADC2_DC - PRESS_REF;
		int u = KP_PRESS * e + KI_PRESS * sum + KD_PRESS * (e - ep);
		if(u < 0)
			u = 0;
		if(u > 100)
			u = 100;
		set_pump(u); 		
	}
}


int main() {
	typedef enum {
		OFF,
		HEATING,
		READY,
		BREWING
	} state = OFF;

	/* initialization */
	init_ui();
	init_sensors();
	...

	/* endless loop */
	while(1) {
		switch(state) {

		case OFF:
			if(test_onoff_button() == 1) {
				state = HEATING;
				set_onoff_led(1);
				start_therm_pid();
				start_therm();
			}
			break;

		case HEATING:
			if(ready == 1)
				state = READY;
			if(test_onoff_button() == 1) {
				state = OFF;
				set_onoff_led(0);
				stop_therm_pid();
				stop_therm();				
			}
			break;

		case READY:
			if(test_onoff_button() == 1) {
				state = OFF;
				stop_therm_pid();
				stop_therm();
				ready = 0;
			}
			else if(test_startstop_button() == 1) {
				set_startstop_led_led(1);
				state =  BREWING;
				start_pump();
				start_pump_pid();
				...
			}
			break;

		case BREWING:
			if(test_startstop_button() == 1) {
				set_startstop_led_led(0);
				stop_pump();
				stop_pump_pid();
				state = READY;
			}
			break;
		}
	}
}

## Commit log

2021-12-03 ajout de toutes les premières ressources
    [Planning.xlsx]
2021-12-03 maj doc suivi de ligne
2021-12-03 maj des Etapes de projet
2021-12-16 photos du chassis
2022-01-11 création dossier des codes
2022-01-11 ajout de fics pour la doc du QTR-8RC
2022-01-11 ajut des libs, makefiles, creation fic moteurs.c, ...
2022-01-12 v1 test capteur de lumière
2022-01-20 ajout des nouvelles photos du monteage du chassis
2022-01-20 ajout de photos du montage
2022-01-25 Ajout des fichiers STL
    [Base Bas.stl, Base Haute .stl, Support Moteur Small.stl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]
2022-01-26 code PWM presque OK
2022-01-26 ajout des états de décalage gauche droite
2022-01-28 moteurs pwm ok
2022-02-01 test suivi de ligne 1
2022-02-01 fonctionnement du suivi de ligne
2022-02-07 nouveau fic pour les couleurs
2022-02-07 fonctionnement 2 du suivi de ligne
2022-02-17 servo ok
2022-02-19 video + fic stl detecteur couleurs
    [detecteur couleur v0.stl]
